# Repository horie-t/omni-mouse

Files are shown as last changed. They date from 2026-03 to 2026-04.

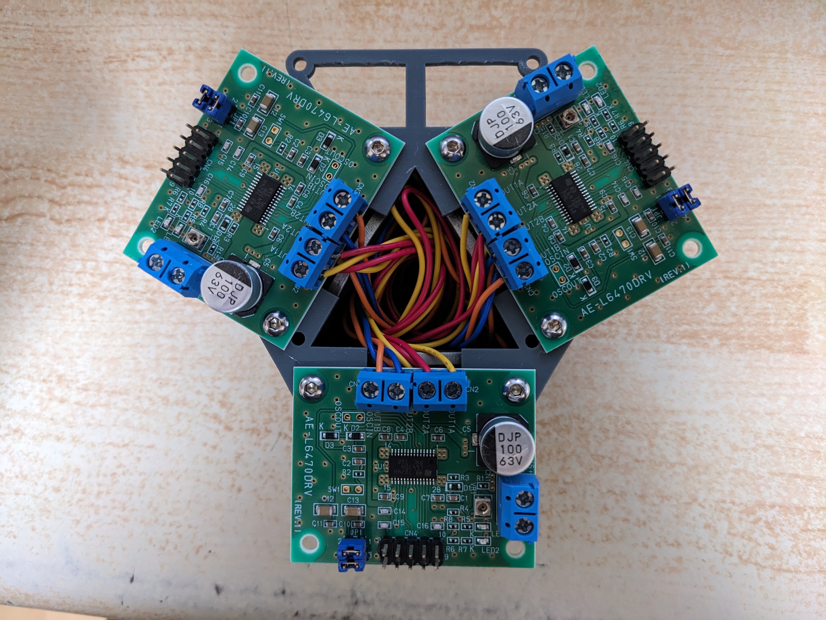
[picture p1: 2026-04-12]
electric/l6470_steping_motor.jpg

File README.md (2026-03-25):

# OmniMouse

This is a project to create a micro mouse using a Raspberry Pi 5 and an omni wheel and compete in a micro mouse competition.

Raspberry Pi 5とオムニホイールを使ったマイクロマウスを制作し、マイクロマウス大会に出場するプロジェクトです。

## ハードウェア構成

Raspberry Pi 5とオムニホイールを組み合わせてマイクロマウスを作成します。ハードウェア構成は以下の通りです。

- Raspberry Pi 5
- オムニホイール (直径: 48 mm, 幅: 25.5 mm) 3個
- ステッピングモーター (ステップ角: 1.8°) 3個
- モータードライバー L6470 3個
- センサー（9軸センサー）
- カメラ (迷路の先読み前方カメラ、壁近接検知見下ろしカメラ)

## ソフトウェア構成

- Raspberry Pi OS (bookworm)
- Java 25
- Spring Boot / WebFlux
- Pi4J
- JavaCV

## Raspberry Pi OSのセットアップ

[こちら](./docs/setup.md)を参照してください。

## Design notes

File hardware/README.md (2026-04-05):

# Omni Mouseハードウェア設計

## 3Dプリンタ

ELEGOO Mars 2での印刷の設定。ELEGOO 光造形3Dプリンター用 水洗い樹脂 UVレジンを使用。

* レイヤーの高さ: 0.05mm
* 初期層の数: 10
* 露光時間: 5s
* 初期層の露光時間: 150s
* 消灯遅延: 7s
* 初期層消灯遅延: 8s
* 初期層リフト距離: 5mm
* リフト高さ: 5mm
* 初期層上昇速度: 30mm/s
* 上昇速度: 50mm/s
* リトラクト速度: 150mm/s

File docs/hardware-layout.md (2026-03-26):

# ハードウェア レイアウト

ロボット座標系におけるホイール（ステッピングモーター）と下向きカメラの位置・向きを記述する。

## ロボット座標系

- **+x**: ロボット前方
- **+y**: ロボット左方向
- **+z**: 上方向
- **角度**: +x から反時計回り（CCW）を正とする

## ホイール配置

3つのオムニホイールを120°等間隔に配置する。
取り付け位置角 φ は +x（前方）から反時計回りに計測する。

```
              前方 (+x)
                ↑
            [W0] φ=0°
           ／       ＼
          ／           ＼
  左 (+y)←               →右 (−y)
          ＼           ／
           ＼         ／
   [W2] φ=240°   [W1] φ=120°
```

| モーター | 取り付け位置角 φ | モーター軸方向（半径方向） | ローラー転がり方向（接線方向） |
|---|---|---|---|
| motor[0] | 0°（前方） | 0° ／ 180°（前後） | 90° ／ 270°（左右） |
| motor[1] | 120°（左後方） | 120° ／ 300° | 210° ／ 30° |
| motor[2] | 240°（右後方） | 240° ／ 60° | 330° ／ 150° |

- **中心半径**: 50 mm（ロボット中心からホイール接地点まで）
- **ホイール半径**: 24 mm（直径 48 mm）

## 下向きカメラ配置

カメラはロボット中心に下向きに固定する。

- **FOV**: 102°
- **画像上端**: ロボット前方（+x）に対応
- **画像右端**: ロボット右方向（−y）に対応

```
        画像上端 = ロボット前方 (+x)
               ↑
        ┌──────────────┐
        │              │
        │              │
左(+y) ←│    カメラ     │→ 右(−y)
        │    (俯瞰)    │
        │              │
        └──────────────┘
               ↓
        画像下端 = ロボット後方 (−x)
```

### VisionModule との対応

`DownwardVisionModule` はカメラ画像を前後左右の4ストリップに分割して壁を検出する。
上記のカメラ搭載向きにより、各ストリップとロボット座標系の対応は以下の通り。

| ストリップ | 画像上の位置 | ロボット方向 | 世界座標方向（East 向き時） |
|---|---|---|---|
| front | 画像上端 | +x（前方） | East |
| back | 画像下端 | −x（後方） | West |
| left | 画像左端 | +y（左方） | North |
| right | 画像右端 | −y（右方） | South |

> ロボットは常に East（θ=0）を向いて探索走行するため、ロボット前方 = 世界東方向 となる。

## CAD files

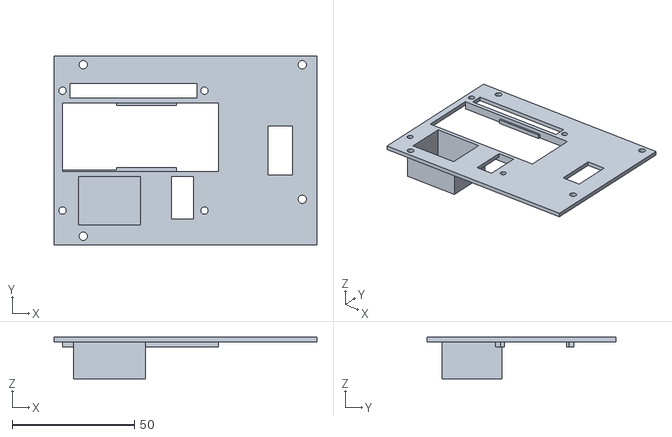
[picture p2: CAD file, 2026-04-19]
hardware/middle_plate-Body.stl
107.5 x 77.1 x 17.0

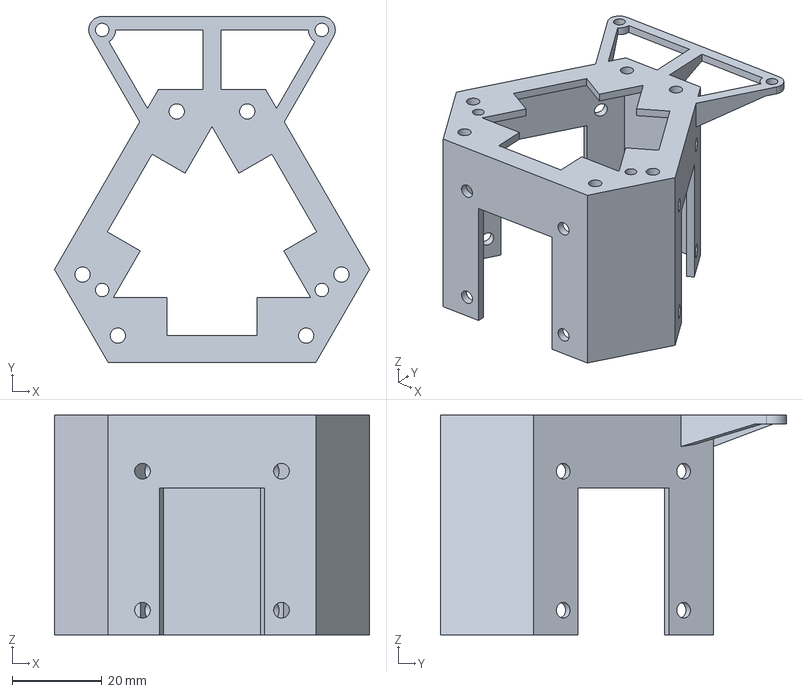
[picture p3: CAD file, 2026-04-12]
hardware/body.FCStd
70.3 x 77.2 x 49.0 mm

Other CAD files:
hardware/middle_plate.FCStd
hardware/body-Body.stl

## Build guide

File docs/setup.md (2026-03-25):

# Raspberry Piのセットアップ

## Javaのセットアップ

### SDKMANのセットアップ
```bash
sudo apt update
sudo apt install zip
curl -s "https://get.sdkman.io" | bash
source "$HOME/.sdkman/bin/sdkman-init.sh"
```

### Javaのバージョン管理
```bash
sdk install java 25.0.2-tem
java -version
```

## カメラのセットアップ

```bash
sudo apt install libcamera-v4l2 rpicam-apps
```

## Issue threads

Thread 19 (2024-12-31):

カメラのマウントを作成する

horie-t, 2024-12-31:

horie-t, 2025-02-15:
[Raspberry Pi カメラモジュール V3（広角）](https://www.switch-science.com/products/8702) (赤外線カットフィルタ付き)を接続。接続には[Raspberry Pi 5 FPCカメラケーブル（200mm）](https://www.switch-science.com/products/9255)を使用する。

CSIコネクタはJ3(LANポート寄りの方)に接続。

動作確認。

```
$ libcamera-still -n -o photo.jpg
[0:02:19.408524629] [2541]  INFO Camera camera_manager.cpp:325 libcamera v0.3.2+27-7330f29b
[0:02:19.416274978] [2544]  INFO RPI pisp.cpp:695 libpisp version v1.0.7 28196ed6edcf 29-08-2024 (16:33:32)
[0:02:19.433359783] [2544]  INFO RPI pisp.cpp:1154 Registered camera /base/axi/pcie@120000/rp1/i2c@88000/imx708@1a to CFE device /dev/media3 and ISP device /dev/media0 using PiSP variant BCM2712_C0
Mode selection for 2304:1296:12:P
    SRGGB10_CSI2P,1536x864/0 - Score: 3400
    SRGGB10_CSI2P,2304x1296/0 - Score: 1000
    SRGGB10_CSI2P,4608x2592/0 - Score: 1900
Stream configuration adjusted
[0:02:19.434166104] [2541]  INFO Camera camera.cpp:1197 configuring streams: (0) 2304x1296-YUV420 (1) 2304x1296-BGGR_PISP_COMP1
[0:02:19.434266288] [2544]  INFO RPI pisp.cpp:1450 Sensor: /base/axi/pcie@120000/rp1/i2c@88000/imx708@1a - Selected sensor format: 2304x1296-SBGGR10_1X10 - Selected CFE format: 2304x1296-PC1B
Mode selection for 4608:2592:12:P
    SRGGB10_CSI2P,1536x864/0 - Score: 10600
    SRGGB10_CSI2P,2304x1296/0 - Score: 8200
    SRGGB10_CSI2P,4608x2592/0 - Score: 1000
Stream configuration adjusted
[0:02:24.596529608] [2541]  INFO Camera camera.cpp:1197 configuring streams: (0) 4608x2592-YUV420 (1) 4608x2592-BGGR_PISP_COMP1
[0:02:24.603582499] [2544]  INFO RPI pisp.cpp:1450 Sensor: /base/axi/pcie@120000/rp1/i2c@88000/imx708@1a - Selected sensor format: 4608x2592-SBGGR10_1X10 - Selected CFE format: 4608x2592-PC1B
Still capture image received
```

horie-t, 2025-02-15:
カメラマウントの[CADデータ](https://github.com/horie-t/omni-mouse/blob/main/hardware/camera_mount.FCStd)

horie-t, 2025-02-15:
24mm

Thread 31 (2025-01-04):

OpenCVの環境構築をする

horie-t, 2025-01-04:

horie-t, 2025-02-15:
```
uv add opencv-python
```

horie-t, 2025-02-15:
```python
$ uv run python
Python 3.12.8 (main, Jan 14 2025, 22:38:09) [GCC 6.3.0 20170516] on linux
Type "help", "copyright", "credits" or "license" for more information.
>>> import cv2
>>>
>>> cv2.__version__
'4.11.0'
```

Closed 2025-02-15.

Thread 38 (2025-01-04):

オドメトリActorを実装する

horie-t, 2025-01-04:
- [x] 正転の方向を反時計回りにできないかを試す
- [x] I/O関係をクラスに切り出すリファクタリング
- [x] 一般的な座標系について調査する
- [ ] ~~座標変換関数を実装する~~
- [x] Odometryメッセージの型を決定する

horie-t, 2025-02-06:
モーター/ドライバ配線変更

元(正転は、時計回り)
左から
* 赤
* 黃
* 橙
* 青

Try 1(ペアを交換)
* 橙
* 青
* 赤
* 黃

正転は半時計まわりになった。

horie-t, 2025-02-13:
オドメトリ用のActorは作成せず、MotionControlActorにオドメトリの機能を追加した。

Closed 2025-02-13.

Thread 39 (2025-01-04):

カメラ画像Actorを実装する

horie-t, 2025-01-04:
- [x] Actor起動
- [x] カメラ・初期化
- [x] カメラ・定期撮影

horie-t, 2025-02-15:
必要なOSの依存パッケージをインストールする。

```
sudo apt install -y python3-libcamera python3-kms++
sudo apt install -y python3-prctl libatlas-base-dev ffmpeg python3-pip
sudo apt install -y python3-pyqt5 python3-opengl
```

horie-t, 2025-02-15:
libcameraが必要と怒られる

```
$ uv run python src/omni_mouse/experiment/camera_module_v3.py
Traceback (most recent call last):
  File "/home/tetsuya/omni-mouse/src/omni_mouse/experiment/camera_module_v3.py", line 2, in <module>
    from picamera2 import Picamera2
  File "/home/tetsuya/omni-mouse/.venv/lib/python3.12/site-packages/picamera2/__init__.py", line 4, in <module>
    import libcamera
ModuleNotFoundError: No module named 'libcamera'
```

horie-t, 2025-02-15:
インストールできない

```
$ uv add libcamera
  × No solution found when resolving dependencies for split (python_full_version == '3.12.*' and sys_platform ==
  │ 'darwin'):
  ╰─▶ Because libcamera was not found in the package registry and your project depends on libcamera, we can conclude
      that your project's requirements are unsatisfiable.
  help: If you want to add the package regardless of the failed resolution, provide the `--frozen` flag to skip
        locking and syncing.
```

horie-t, 2025-02-15:
開発用のパッケージをインストールしてrpi-libcamearをインストールしようとしたがバージョン依存で弾かれる。

```
$ sudo apt install -y libcamera-dev
Reading package lists... Done
Building dependency tree... Done
Reading state information... Done
The following NEW packages will be installed:
  libcamera-dev
0 upgraded, 1 newly installed, 0 to remove and 134 not upgraded.
Need to get 37.1 kB of archives.
After this operation, 190 kB of additional disk space will be used.
Get:1 http://archive.raspberrypi.com/debian bookworm/main arm64 libcamera-dev arm64 0.4.0+rpt20250213-1 [37.1 kB]
Fetched 37.1 kB in 2s (16.0 kB/s)                 
Selecting previously unselected package libcamera-dev:arm64.
(Reading database ... 128877 files and directories currently installed.)
Preparing to unpack .../libcamera-dev_0.4.0+rpt20250213-1_arm64.deb ...
Unpacking libcamera-dev:arm64 (0.4.0+rpt20250213-1) ...
Setting up libcamera-dev:arm64 (0.4.0+rpt20250213-1) ...
```

```
$ uv add rpi-libcamera
Resolved 70 packages in 138ms
   Built omni-mouse @ file:///home/tetsuya/omni-mouse                                                                     × Failed to build `rpi-libcamera==0.1a8`
  ├─▶ The build backend returned an error
  ╰─▶ Call to `mesonpy.build_wheel` failed (exit status: 1)

      [stdout]
      + meson setup /home/tetsuya/.cache/uv/sdists-v6/pypi/rpi-libcamera/0.1a8/S4Hquzt6VB_yN8UQjvmdu/src
      /home/tetsuya/.cache/uv/sdists-v6/pypi/rpi-libcamera/0.1a8/S4Hquzt6VB_yN8UQjvmdu/src/.mesonpy-tbz4y5j1
      -Dbuildtype=release -Db_ndebug=if-release -Db_vscrt=md -Drevision=v0.4.0+rpt20250127
      -Drepository=https://github.com/raspberrypi/libcamera.git -Dversion=v0.4.0+50-83cb8101
      --native-file=/home/tetsuya/.cache/uv/sdists-v6/pypi/rpi-libcamera/0.1a8/S4Hquzt6VB_yN8UQjvmdu/src/.mesonpy-tbz4y5j1/meson-python-native-file.ini
      The Meson build system
      Version: 1.7.0
      Source dir: /home/tetsuya/.cache/uv/sdists-v6/pypi/rpi-libcamera/0.1a8/S4Hquzt6VB_yN8UQjvmdu/src
      Build dir: /home/tetsuya/.cache/uv/sdists-v6/pypi/rpi-libcamera/0.1a8/S4Hquzt6VB_yN8UQjvmdu/src/.mesonpy-tbz4y5j1
      Build type: native build
      Project name: pylibcamera
      Project version: 0.1.0
      C compiler for the host machine: cc (gcc 12.2.0 "cc (Debian 12.2.0-14) 12.2.0")
      C linker for the host machine: cc ld.bfd 2.40
      C++ compiler for the host machine: c++ (gcc 12.2.0 "c++ (Debian 12.2.0-14) 12.2.0")
      C++ linker for the host machine: c++ ld.bfd 2.40
      Host machine cpu family: aarch64
      Host machine cpu: aarch64
      Message: Cloning from: https://github.com/raspberrypi/libcamera.git, revision v0.4.0+rpt20250127
      Message: libcamera version is v0.4.0+53-29156679

      ../meson.build:26:8: ERROR: Problem encountered: This package works with libcamera version v0.4.0+50-83cb8101,
      but you have version v0.4.0+53-29156679
       installed. Please check the readme for help with this error

      A full log can be found at
      /home/tetsuya/.cache/uv/sdists-v6/pypi/rpi-libcamera/0.1a8/S4Hquzt6VB_yN8UQjvmdu/src/.mesonpy-tbz4y5j1/meson-logs/meson-log.txt

      hint: This usually indicates a problem with the package or the build environment.
  help: `rpi-libcamera` (v0.1a8) was included because `omni-mouse` (v0.1.0) depends on `rpi-libcamera`
```

horie-t, 2025-02-15:
インストール可能なバージョンを調べてみる。

```
$ sudo apt-cache showpkg libcamera-dev
Package: libcamera-dev
Versions:
0.4.0+rpt20250213-1 (/var/lib/apt/lists/archive.raspberrypi.com_debian_dists_bookworm_main_binary-arm64_Packages)
 Description Language:
                 File: /var/lib/apt/lists/deb.debian.org_debian_dists_bookworm_main_binary-arm64_Packages
                  MD5: a817fddde055009800fbb7c2566de922
 Description Language:
                 File: /var/lib/apt/lists/deb.debian.org_debian_dists_bookworm_main_binary-armhf_Packages
                  MD5: a817fddde055009800fbb7c2566de922
 Description Language: en
                 File: /var/lib/apt/lists/deb.debian.org_debian_dists_bookworm_main_i18n_Translation-en
                  MD5: a817fddde055009800fbb7c2566de922
 Description Language:
                 File: /var/lib/apt/lists/archive.raspberrypi.com_debian_dists_bookworm_main_binary-arm64_Packages
                  MD5: a817fddde055009800fbb7c2566de922
 Description Language:
                 File: /var/lib/apt/lists/archive.raspberrypi.com_debian_dists_bookworm_main_binary-armhf_Packages
                  MD5: a817fddde055009800fbb7c2566de922

0.0.3-6 (/var/lib/apt/lists/deb.debian.org_debian_dists_bookworm_main_binary-arm64_Packages)
 Description Language:
                 File: /var/lib/apt/lists/deb.debian.org_debian_dists_bookworm_main_binary-arm64_Packages
                  MD5: a817fddde055009800fbb7c2566de922
 Description Language:
                 File: /var/lib/apt/lists/deb.debian.org_debian_dists_bookworm_main_binary-armhf_Packages
                  MD5: a817fddde055009800fbb7c2566de922
 Description Language: en
                 File: /var/lib/apt/lists/deb.debian.org_debian_dists_bookworm_main_i18n_Translation-en
                  MD5: a817fddde055009800fbb7c2566de922
 Description Language:
                 File: /var/lib/apt/lists/archive.raspberrypi.com_debian_dists_bookworm_main_binary-arm64_Packages
                  MD5: a817fddde055009800fbb7c2566de922
 Description Language:
                 File: /var/lib/apt/lists/archive.raspberrypi.com_debian_dists_bookworm_main_binary-armhf_Packages
                  MD5: a817fddde055009800fbb7c2566de922

Reverse Depends:
  libcamera-dev:armhf,libcamera-dev 0.4.0+rpt20250213-1
  libcamera-dev:armhf,libcamera-dev 0.4.0+rpt20250213-1
  libcamera-dev:armhf,libcamera-dev 0.0.3-6
  libcamera-doc,libcamera-dev
  libcamera-dev:armhf,libcamera-dev 0.0.3-6
  libcamera-doc,libcamera-dev
Dependencies:
0.4.0+rpt20250213-1 - libcamera0.4 (5 0.4.0+rpt20250213-1) libcamera-dev:armhf (35 0.4.0+rpt20250213-1) libcamera-dev:armhf (38 0.4.0+rpt20250213-1)
0.0.3-6 - libcamera0.0.3 (5 0.0.3-6) libcamera-dev:armhf (35 0.0.3-6) libcamera-dev:armhf (38 0.0.3-6)
Provides:
0.4.0+rpt20250213-1 -
0.0.3-6 -
Reverse Provides:
```

horie-t, 2025-02-15:
[こちら](https://forums.raspberrypi.com/viewtopic.php?t=361758)を試す。

```
sudo apt update && sudo apt upgrade
sudo apt install libcap-dev libatlas-base-dev ffmpeg libopenjp2-7
sudo apt install libcamera-dev
sudo apt install libkms++-dev libfmt-dev libdrm-dev
```

これでも、uv addできない。

horie-t, 2025-02-15:
[Pylibcamera](https://github.com/raspberrypi/pylibcamera)をforkしてlibcameraのバージョンとその時のタグを変更した。

```diff
 [project]
 name = 'rpi-libcamera'
-version = '0.1a8'
+version = '0.1a11'
 description = 'libcamera python bindings'
 readme = 'README.md'

@@ -14,9 +14,9 @@ Source = "https://github.com/raspberrypi/pylibcamera"

 [tool.meson-python.args]
 setup = [
-    '-Drevision=v0.4.0+rpt20250127',
+    '-Drevision=v0.4.0+rpt20250213',
     '-Drepository=https://github.com/raspberrypi/libcamera.git',
-    '-Dversion=v0.4.0+50-83cb8101'
+    '-Dversion=v0.4.0+53-29156679'
 ]

 [tool.flit.module]
```

```
uv add git+https://github.com/horie-t/pylibcamera.git@v0.1a11
```

```
uv add rpi-kms picamera2
```

horie-t, 2025-02-15:
やっと、写真が取れた。

Closed 2025-02-16.

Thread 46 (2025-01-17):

uvでプロジェクトを作成する

horie-t, 2025-01-17:

horie-t, 2025-01-21:
uvのインストール

```
curl -LsSf https://astral.sh/uv/install.sh | sh
```

シェルを再起動。

コマンドの入力補完を設定する

```
echo 'eval "$(uv generate-shell-completion bash)"' >> ~/.bashrc
echo 'eval "$(uvx --generate-shell-completion bash)"' >> ~/.bashrc
```

シェルを再起動

Pythonのバージョンを更新

```
uv python install cpython-3.13.1-linux-aarch64-gnu
```

プロジェクトを作成する

```
uv init --app --package omni-mouse
```

```
cd omni-mouse
```

```
uv sync
source .venv/bin/activate
```

main用のファイルを作成する

```python:src/omni_mouse/__main__.py
from omni_mouse import main

if __name__ == "__main__":
    main()
```

パッケージをビルドする。

```
uv build
```

アプリケーションを実行する

```
$ omni-mouse
Hello from omni-mouse!
```

Closed 2025-01-21.

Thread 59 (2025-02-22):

マップマッチ: 境界線を抽出する

horie-t, 2025-02-22:

horie-t, 2025-02-24:
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

この写真をベースに作業を進めてみる。

horie-t, 2025-02-24:
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

この写真をベースに作業を進めてみる。

horie-t, 2025-03-01:
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

をベースに作業。

horie-t, 2025-03-01:
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

2値化後の画像。

horie-t, 2025-03-01:
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

輪郭の抽出。

horie-t, 2025-03-01:
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

コーナーの抽出

horie-t, 2025-03-01:
輪郭かコーナーの抽出結果のうち、どちらか使いやすい方を使う。

コーナーの抽出は、近くの点が並ばないので、輪郭の抽出結果の方が使いやすそう。

Closed 2025-03-01.

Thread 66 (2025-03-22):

魚眼レンズ用カメラマウントを制作

horie-t, 2025-03-22:
- [x] 概略を設計
- [x] カメラモジュールの基板サイズ調査
- [x] FreeCAD設計
- [x] 3Dプリント

horie-t, 2025-03-22:
[Raspberry Pi用魚眼レンズカメラモジュール（8MP / IMX219）](https://www.switch-science.com/products/8245)を使用。

基板の形状は[公式](https://datasheets.raspberrypi.com/camera/camera-module-2-mechanical-drawing.pdf)と同じ。

horie-t, 2025-03-22:
概略図

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

Closed 2025-04-05.

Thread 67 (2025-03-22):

カメラの校正

horie-t, 2025-03-22:
- [x] Pythonで色補正をして画像を取得する
- [x] 校正用の画像を取得する
- [x] 校正データを生成する
- [x] 校正データを使って画像を校正する

horie-t, 2025-03-30:
Picamera2でのチューニングファイルの[使い方](https://github.com/raspberrypi/picamera2/blob/main/examples/tuning_file.py)

horie-t, 2025-03-30:
https://github.com/raspberrypi/picamera2/blob/fb031cb49cb2af4dab7439be7a90784c9d3db1ab/picamera2/picamera2.py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 を見ると、

`/usr/share/libcamera/ipa/rpi/pisp`にコピーしてしまうのがいいかな。

Closed 2025-04-13.

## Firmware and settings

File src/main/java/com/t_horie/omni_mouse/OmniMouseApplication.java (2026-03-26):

package com.t_horie.omni_mouse;

import com.pi4j.Pi4J;
import com.pi4j.context.Context;
import com.pi4j.io.spi.SpiChipSelect;
import com.pi4j.io.spi.SpiBus;
import com.t_horie.omni_mouse.control.motion.MotionControlModule;
import com.t_horie.omni_mouse.control.motion.OmniMotionModule;
import com.t_horie.omni_mouse.control.path.PIDPathFollower;
import com.t_horie.omni_mouse.control.path.PathFollowingModule;
import com.t_horie.omni_mouse.control.stabilization.HeadingStabilizer;
import com.t_horie.omni_mouse.hardware.camera.RpicamCameraModule;
import com.t_horie.omni_mouse.hardware.imu.Bno055IMUModule;
import com.t_horie.omni_mouse.hardware.motor.L6470MotorModule;
import com.t_horie.omni_mouse.planning.exploration.FloodFillExplorationModule;
import com.t_horie.omni_mouse.planning.mapping.CellCoord;
import com.t_horie.omni_mouse.planning.mapping.WallMappingModule;
import com.t_horie.omni_mouse.sensing.odometry.FusedOdometryModule;
import com.t_horie.omni_mouse.sensing.vision.DownwardVisionModule;
import org.springframework.boot.CommandLineRunner;
import org.springframework.boot.SpringApplication;
import org.springframework.boot.autoconfigure.SpringBootApplication;
import org.springframework.context.annotation.Bean;

import java.util.Set;

@SpringBootApplication
public class OmniMouseApplication {

	private static final SpiBus        SPI_BUS    = SpiBus.BUS_0;
	private static final SpiChipSelect SPI_CS     = SpiChipSelect.CS_0;
	private static final byte          KVAL       = 0x40;
	private static final int           I2C_BUS    = 1;
	private static final int           CAMERA_IDX = 0;

	// 4x4 迷路のゴールセル（右上隅）
	private static final CellCoord GOAL = new CellCoord(3, 3);

	public static void main(String[] args) {
		SpringApplication.run(OmniMouseApplication.class, args);
	}

	@Bean
	public CommandLineRunner run() {
		return args -> {
			Context pi4j = Pi4J.newAutoContext();

			// ── Hardware layer ──────────────────────────────────────────────
			var motors = new L6470MotorModule(pi4j, SPI_BUS, SPI_CS, KVAL);
			var imu    = new Bno055IMUModule(pi4j, I2C_BUS);

			// ── Control layer ───────────────────────────────────────────────
			MotionControlModule motion = new HeadingStabilizer(new OmniMotionModule(motors), imu);
			PathFollowingModule follower = new PIDPathFollower();

			// ── Sensing layer ───────────────────────────────────────────────
			var odometry = new FusedOdometryModule(imu, motors);

			// ── Vision / Mapping / Exploration layer ────────────────────────
			var camera    = new RpicamCameraModule(CAMERA_IDX, 640, 480, 30);
			var vision    = new DownwardVisionModule();
			var mapping   = new WallMappingModule();
			var exploration = new FloodFillExplorationModule(Set.of(GOAL));

			Runtime.getRuntime().addShutdownHook(new Thread(() -> {
				System.out.println("Shutting down...");
				motion.close();
				imu.shutdown();
				pi4j.shutdown();
			}));

			// オドメトリストリーム開始（100 Hz、内部状態を更新）
			odometry.start().subscribe(
					odom -> {},
					err  -> System.err.println("Odometry error: " + err.getMessage())
			);

			// ── 4x4 迷路 探索走行 ───────────────────────────────────────────
			System.out.printf("Starting maze exploration (goal: %s)%n", GOAL);
			var explorer = new MazeExplorer(camera, vision, mapping, exploration, follower, motion, odometry);
			explorer.run();

			System.out.println("Exploration complete.");
			Thread.sleep(500);
			motion.freeRun();
		};
	}
}

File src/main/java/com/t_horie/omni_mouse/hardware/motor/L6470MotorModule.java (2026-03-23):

package com.t_horie.omni_mouse.hardware.motor;

import com.pi4j.context.Context;
import com.pi4j.io.spi.Spi;
import com.pi4j.io.spi.SpiChipSelect;
import com.pi4j.io.spi.SpiMode;
import com.pi4j.io.spi.SpiBus;

/**
 * L6470 stepper motor driver — daisy-chain implementation.
 *
 * <h2>Daisy-chain wiring</h2>
 * <pre>
 *   RPi MOSI → motor[0].SDI → motor[0].SDO
 *                            → motor[1].SDI → motor[1].SDO
 *                                           → motor[2].SDI → motor[2].SDO → RPi MISO
 *   RPi SCLK and CE shared by all three chips.
 * </pre>
 *
 * <h2>Daisy-chain SPI protocol</h2>
 * An M-byte command to N motors requires M separate CS transactions (one per byte
 * position). Each transaction contains exactly N bytes:
 * {@code [motor[N-1].byte[k], ..., motor[1].byte[k], motor[0].byte[k]]}
 * Because motor[0] (closest to MOSI) receives the LAST byte of each N-byte group
 * (standard shift-register behaviour), and motor[N-1] (closest to MISO) receives
 * the first.
 *
 * <h2>SPI settings</h2>
 * Mode 3 (CPOL=1, CPHA=1), MSB first, up to 5 MHz (L6470 datasheet Table 15).
 *
 * <h2>Speed register</h2>
 * speed_reg = steps_per_sec × 250 ns × 2^28  (datasheet section 9.1.4)
 */
public class L6470MotorModule implements MotorControlModule, MotorEncoderModule {

    public static final int MOTOR_COUNT = 3;

    // --- Register addresses ---
    private static final byte REG_ABS_POS  = 0x01;  // 22-bit signed position in steps
    private static final byte REG_STEP_MODE = 0x16;
    private static final byte REG_KVAL_HOLD = 0x09;
    private static final byte REG_KVAL_RUN  = 0x0A;
    private static final byte REG_KVAL_ACC  = 0x0B;
    private static final byte REG_KVAL_DEC  = 0x0C;

    // --- Commands ---
    private static final byte CMD_RUN_FORWARD     = 0x51;       // Run forward
    private static final byte CMD_RUN_REVERSE     = 0x50;       // Run reverse
    private static final byte CMD_HARD_STOP       = (byte) 0xB8; // Stop with braking
    private static final byte CMD_HARD_HIZ        = (byte) 0xA8; // Coils off
    private static final byte CMD_RESET_DEVICE    = (byte) 0xC0; // Soft reset
    private static final byte CMD_GET_PARAM_ABS_POS = (byte) (0x20 | 0x01); // GetParam ABS_POS

    // --- Step mode ---
    private static final byte STEP_MODE_FULL = 0x00;

    // --- Physical constants ---
    private static final int    STEPS_PER_REV  = 200;    // typical 2-phase stepper
    private static final double TICK_DURATION_S = 250e-9; // 250 ns at 16 MHz

    private final Spi spi;

    /**
     * @param pi4j       Pi4J context
     * @param bus        SPI bus (BUS_0 = /dev/spidev0.x)
     * @param chipSelect chip-select line shared by all 3 motors (CE0 or CE1)
     * @param kval       coil voltage ratio for all motors (0x00–0xFF = 0–100% of Vcc).
     *                   Start with 0x40 (25%) and adjust for your motor/supply.
     */
    public L6470MotorModule(Context pi4j, SpiBus bus, SpiChipSelect chipSelect, byte kval) {
        var spiConfig = Spi.newConfigBuilder(pi4j)
                .id("L6470-" + bus + "-" + chipSelect)
                .bus(bus)
                .chipSelect(chipSelect)
                .baud(4_000_000)       // 4 MHz (max 5 MHz)
                .mode(SpiMode.MODE_3)  // CPOL=1, CPHA=1
                .build();
        this.spi = pi4j.spi().create(spiConfig);
        initialize(kval);
    }

    // -------------------------------------------------------------------------
    // MotorControlModule interface
    // -------------------------------------------------------------------------

    @Override
    public int getMotorCount() {
        return MOTOR_COUNT;
    }

    /**
     * Run all motors simultaneously.
     *
     * @param revsPerSec array of length 3; positive = forward, negative = reverse
     */
    @Override
    public void run(double[] revsPerSec) {
        if (revsPerSec.length != MOTOR_COUNT) {
            throw new IllegalArgumentException(
                    "Expected " + MOTOR_COUNT + " speeds, got " + revsPerSec.length);
        }

        // Build 4-byte command per motor: [cmd, speed_hi, speed_mid, speed_lo]
        byte[][] cmds = new byte[MOTOR_COUNT][4];
        for (int i = 0; i < MOTOR_COUNT; i++) {
            double spd = revsPerSec[i];
            int speedReg = toSpeedReg(Math.abs(spd) * STEPS_PER_REV);
            cmds[i][0] = spd >= 0 ? CMD_RUN_FORWARD : CMD_RUN_REVERSE;
            cmds[i][1] = (byte) ((speedReg >> 16) & 0x0F);
            cmds[i][2] = (byte) ((speedReg >> 8)  & 0xFF);
            cmds[i][3] = (byte) (speedReg         & 0xFF);
        }
        sendMultiByte(cmds);
    }

    @Override
    public void stop() {
        sendUniform(CMD_HARD_STOP, 1);
    }

    @Override
    public void freeRun() {
        sendUniform(CMD_HARD_HIZ, 1);
    }

    @Override
    public void close() {
        stop();
        freeRun();
        spi.close();
    }

    // -------------------------------------------------------------------------
    // MotorEncoderModule interface
    // -------------------------------------------------------------------------

    /**
     * Read the absolute position of all motors from the L6470 ABS_POS register.
     *
     * <p>ABS_POS is a 22-bit signed integer (steps from the power-on reference).
     * After device reset, ABS_POS = 0. In full-step mode, each step increments
     * or decrements the count by 1.
     *
     * <p>Daisy-chain read sequence (3 motors, 3 response bytes per motor):
     * <ol>
     *   <li>1 CS transaction: send GetParam command [0x21 × 3]</li>
     *   <li>3 CS transactions: send dummy bytes, receive 1 byte per motor each time</li>
     * </ol>
     *
     * @return absolute positions in revolutions; positive = forward direction
     */
    @Override
    public double[] getAbsolutePositions() {
        // Issue GetParam ABS_POS to all motors
        sendUniform(CMD_GET_PARAM_ABS_POS, 1);

        // Read 3-byte response from each motor (22-bit value, MSB first)
        byte[][] raw = receiveMultiByte(3);

        double[] revolutions = new double[MOTOR_COUNT];
        for (int i = 0; i < MOTOR_COUNT; i++) {
            int pos24 = ((raw[i][0] & 0xFF) << 16)
                      | ((raw[i][1] & 0xFF) << 8)
                      |  (raw[i][2] & 0xFF);
            // Sign-extend from bit 21 to 32-bit int
            int steps = (pos24 & 0x3F_FFFF) << 10 >> 10;
            revolutions[i] = (double) steps / STEPS_PER_REV;
        }
        return revolutions;
    }

    // -------------------------------------------------------------------------
    // Daisy-chain SPI helpers
    // -------------------------------------------------------------------------
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

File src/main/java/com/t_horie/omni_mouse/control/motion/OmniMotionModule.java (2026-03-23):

package com.t_horie.omni_mouse.control.motion;

import com.t_horie.omni_mouse.hardware.motor.MotorControlModule;

/**
 * Omnidirectional motion controller for a 3-wheel omni robot.
 *
 * <h2>Wheel layout (default)</h2>
 * <pre>
 *          [W0] φ=0°
 *            ↑ (front)
 *           / \
 *          /   \
 *    [W2] /     \ [W1]
 *   φ=240°       φ=120°
 * </pre>
 * All wheels are 120° apart, at radius {@value #CENTER_RADIUS_M} m from the robot centre.
 *
 * <h2>Inverse kinematics</h2>
 * For wheel i at position angle φᵢ (measured counterclockwise from robot +x/forward):
 * <pre>
 *   v_wheel_i = −sin(φᵢ)·Vx + cos(φᵢ)·Vy + r·ω
 *   revsPerSec[i] = v_wheel_i / (2π × r_wheel)
 * </pre>
 * The positive wheel direction corresponds to counterclockwise motion around the robot.
 */
public class OmniMotionModule implements MotionControlModule {

    /** Distance from robot centre to each wheel contact point (m). */
    public static final double CENTER_RADIUS_M = 0.050;

    /** Wheel radius = diameter 48 mm / 2 (m). */
    public static final double WHEEL_RADIUS_M = 0.024;

    /**
     * Position angles of the three wheels in degrees, counterclockwise from robot forward (+x).
     * motor[0] → 0° (front), motor[1] → 120° (back-left), motor[2] → 240° (back-right).
     */
    private static final double[] WHEEL_ANGLES_DEG = {0.0, 120.0, 240.0};

    private final MotorControlModule motors;

    // Pre-computed sin/cos of wheel angles to avoid repeated trig calls
    private final double[] sinPhi = new double[3];
    private final double[] cosPhi = new double[3];

    public OmniMotionModule(MotorControlModule motors) {
        this.motors = motors;
        for (int i = 0; i < 3; i++) {
            double rad = Math.toRadians(WHEEL_ANGLES_DEG[i]);
            sinPhi[i] = Math.sin(rad);
            cosPhi[i] = Math.cos(rad);
        }
    }

    /**
     * Command robot body velocity in the robot frame.
     *
     * @param vx    forward velocity (m/s)
     * @param vy    leftward velocity (m/s)
     * @param omega angular velocity (rad/s), positive = counterclockwise
     */
    @Override
    public void move(double vx, double vy, double omega) {
        double[] revsPerSec = inverseKinematics(vx, vy, omega);
        motors.run(revsPerSec);
    }

    @Override
    public void stop() {
        motors.stop();
    }

    @Override
    public void freeRun() {
        motors.freeRun();
    }

    @Override
    public void close() {
        motors.close();
    }

    // -------------------------------------------------------------------------
    // Inverse kinematics
    // -------------------------------------------------------------------------

    /**
     * Compute per-wheel speeds from robot body velocity.
     *
     * <p>Derivation: the velocity component of the robot at wheel i's contact point,
     * projected onto the wheel's rolling direction (tangential, counterclockwise):
     * <pre>
     *   v_i = −sin(φᵢ)·Vx + cos(φᵢ)·Vy + r_centre·ω
     * </pre>
     *
     * @return revsPerSec[0..2] for motor[0..2]; positive = counterclockwise tangential roll
     */
    double[] inverseKinematics(double vx, double vy, double omega) {
        double[] revsPerSec = new double[3];
        for (int i = 0; i < 3; i++) {
            double wheelLinearVelocity = -sinPhi[i] * vx + cosPhi[i] * vy + CENTER_RADIUS_M * omega;
            revsPerSec[i] = wheelLinearVelocity / (2.0 * Math.PI * WHEEL_RADIUS_M);
        }
        return revsPerSec;
    }
}

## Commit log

2026-03-17 Mavenプロジェクトを作成する
2026-03-20 Lチカを実装する
2026-03-20 3Dプリンタのstlを作成する
    [body_1.FCStd]
2026-03-21 システム構成図を作成する
2026-03-21 Spring WebFluxに変更する
2026-03-21 Springのzipファイルを削除する
2026-03-21 定期的に標準出力にHello, world!を出力する
2026-03-21 WebFluxでLチカを実行する
2026-03-21 BNO055 9軸センサーを接続する
2026-03-21 使わないテストコードを削除する
2026-03-21 READMEを追加する
2026-03-21 9軸センサーの接続をリファクタリングする
2026-03-21 バージョンを設定する
2026-03-21 IMUからの入力のみのOdometory Moduleを実装する
2026-03-22 L6470ステッピングモータを1つ接続する
2026-03-22 ステッピング・モータ 3台をデイジーチェーンで接続する
2026-03-22 L6470モータ・ドライバのデイジーチェーンの制御のバグを修正する
2026-03-22 モーターの電圧を調整する
2026-03-23 MotionControlModuleを実装する
2026-03-23 Motor Encoder相当の機能を実装する
2026-03-23 OdometryModuleを改善する
2026-03-23 StabilizetionModuleを実装する
2026-03-24 PathFollowingModuleを実装する
2026-03-24 バージョンを0.2.0に上げる
2026-03-24 車体のイメージを作成する
2026-03-24 カメラの位置を追加する
2026-03-24 見下ろしカメラを追加する
2026-03-24 カメラを2台に修正する
2026-03-25 カメラを1台接続して写真を取る
    java -Dloader.main=com.t_horie.omni_mouse.hardware.camera.CameraCaptureTest -jar omni-mouse-0.2.0.jar /tmp/test.jpg
    のように実行する
2026-03-25 バージョンを上げる
2026-03-25 セットアップ方法やシステム構成の説明を記述する
2026-03-25 下向きカメラで画像を撮影できるようにする
2026-03-25 Claude codeの初期化
2026-03-26 VisionModuleを実装する
2026-03-26 プロジェクトの名前と説明を記述する
2026-03-26 MappingModuleを実装する
2026-03-26 ExlorationModuleを実装する
2026-03-26 4 x 4マスの迷路を探索走行する
2026-03-26 モーターとカメラの位置関係を明記する
2026-03-26 マウスのイメージ図を修正する
2026-04-05 車台を設計する
    [body-Body.stl, body.FCStd, body_1.FCStd]
2026-04-12 車台のハードウェアを設計する
    [body-Body.stl, body.FCStd]
2026-04-12 L6470モータドライバとステッピングモータの接続写真を撮影する
2026-04-17 Raspberry Piとバッテリーの中間部分を設計する
    [middle_plate.FCStd]
2026-04-17 Raspberry Piとバッテリーの中間部分を設計する(stlファイル出力)
    [middle_plate-Body.stl]
2026-04-19 FreeCADのバックアップファイルは管理対象外にする
2026-04-19 Raspberry Piとバッテリーの中間部分を改良する
    [middle_plate-Body.stl, middle_plate.FCStd]
2026-04-25 CLAUDE.mdを更新する
2026-04-25 IMU動作確認用のテストクラスを作成する
